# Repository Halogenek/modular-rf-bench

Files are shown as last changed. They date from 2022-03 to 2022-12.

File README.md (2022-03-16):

# Modular RF Bench

I came across an awesome system for rapid prototyping RF and Microwave solutions
by connecting individual components on small PCBs, just like LEGO.
This [Modular building block system for RF and microwave design of prototypes](https://patents.google.com/patent/US10784633B2/en?assignee=X-Microwave&oq=X-Microwave) is in my opinion a very clever way of building RF
circuits. On their [website](https://www.xmicrowave.com/) the sell almost every
available modern RF IC or passive network in a form of a rectangle PCBs.
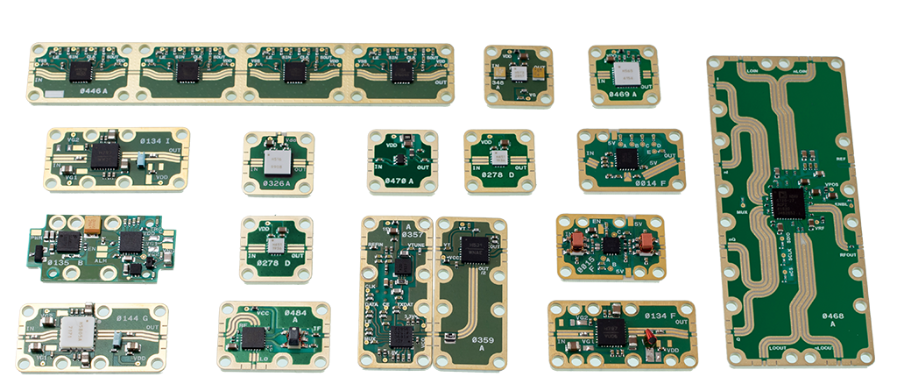
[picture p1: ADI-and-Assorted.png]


The whole system is well polished and every part has some sort of improvement.
For example the boards interconnection has a ground cutout, probably for better
impedance matching. The connection is done (according to their patent) with a
small piece with diamond particles that improve contact. That's why they claim
that this system can be used up to ~67 GHz.

Of course this performance comes at a price.

# My own design
I liked this idea so much that I wanted to check how *bad* will standard FR4
boards perform if someone would make a system like this one. But without all
those whistles.

So I made ten different designs inspired by that system. Ordered it on PcbWay.
And when will it arrive I will test it with my VNA.
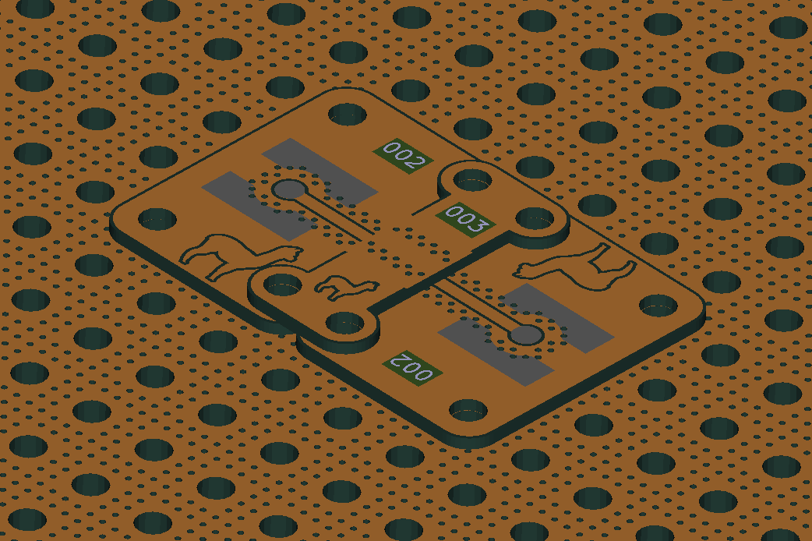
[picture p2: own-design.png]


---
After some time the boards arrived in decent quality. I soldered SMA connectors
to two boards designed for them and screwed them to the PCB base, together with
a small interconnecting PCB.

I tried to follow X Microwave design but my idea had some problems. The small
board with the number 011 that was designed to connect other boards didn't make
good contact after mounted with screws. It just bulged up and the center signal
trace didn't touched the traces on the other PCBs. But after adding a small
amount of solder to the trace it started to work.

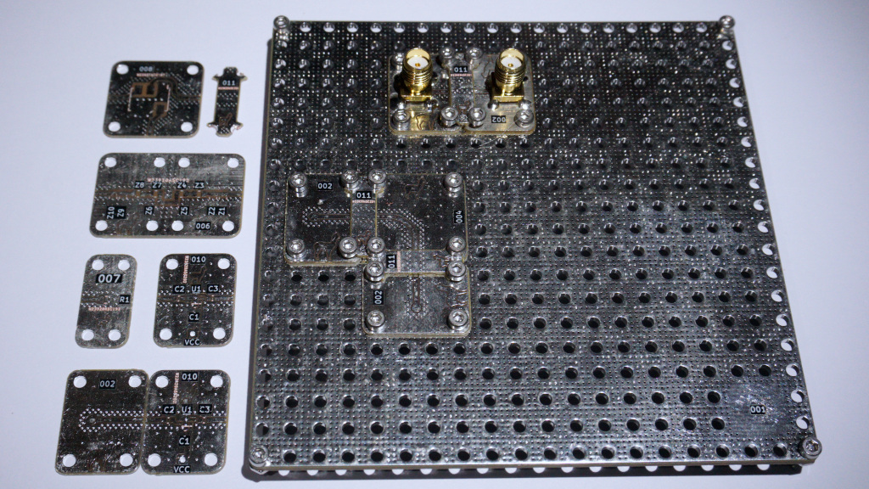
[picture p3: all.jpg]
All ordered boards

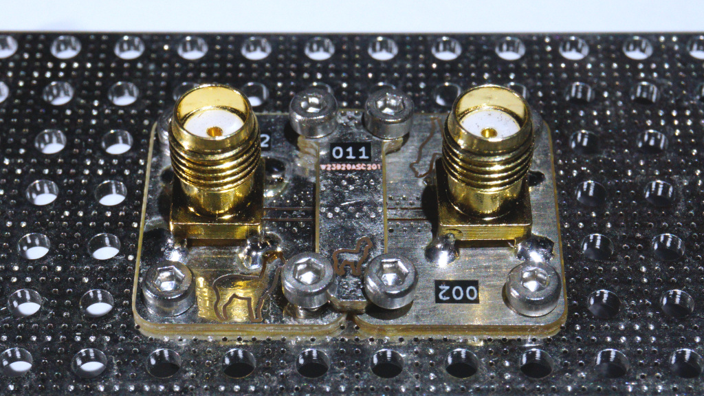
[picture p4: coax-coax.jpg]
Coax to coax connection

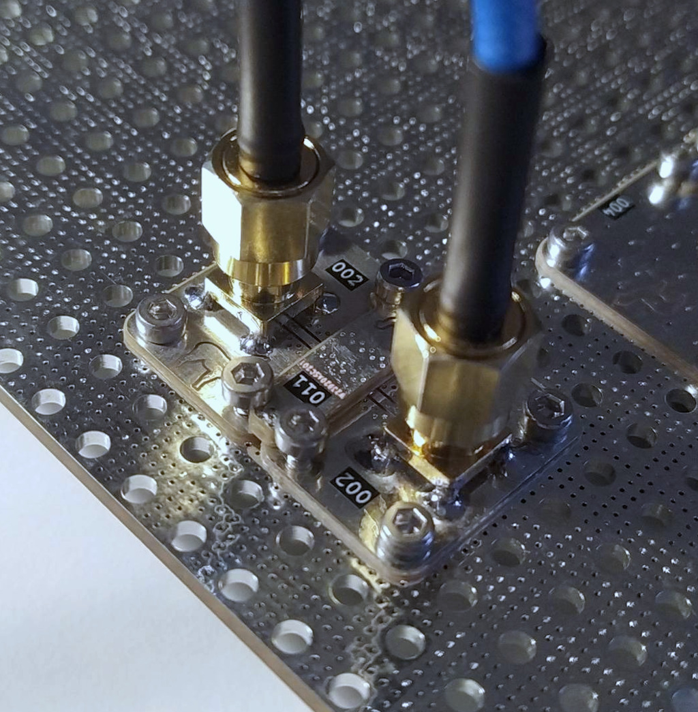
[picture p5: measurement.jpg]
Transmission line measurement


## Measurements
### Measurements of two connected SMA adapters done on nanoVNA.
*S11 50 Ohm termination*
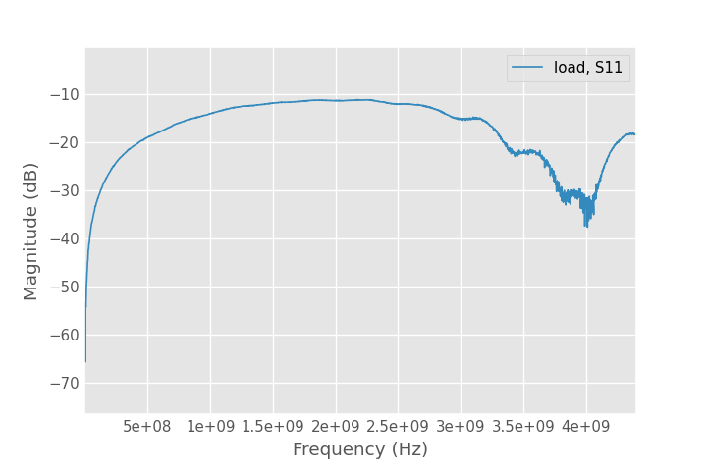
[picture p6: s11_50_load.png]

*S11 50 Ohm termination by Port 2 of nanoVNA*
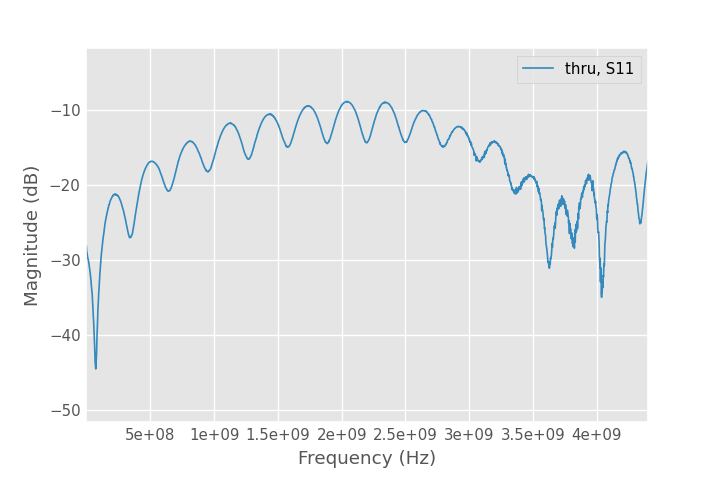
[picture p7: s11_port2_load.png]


### Measurements of two connected SMA adapters done on better VNA.
*S11 50 Ohm termination*
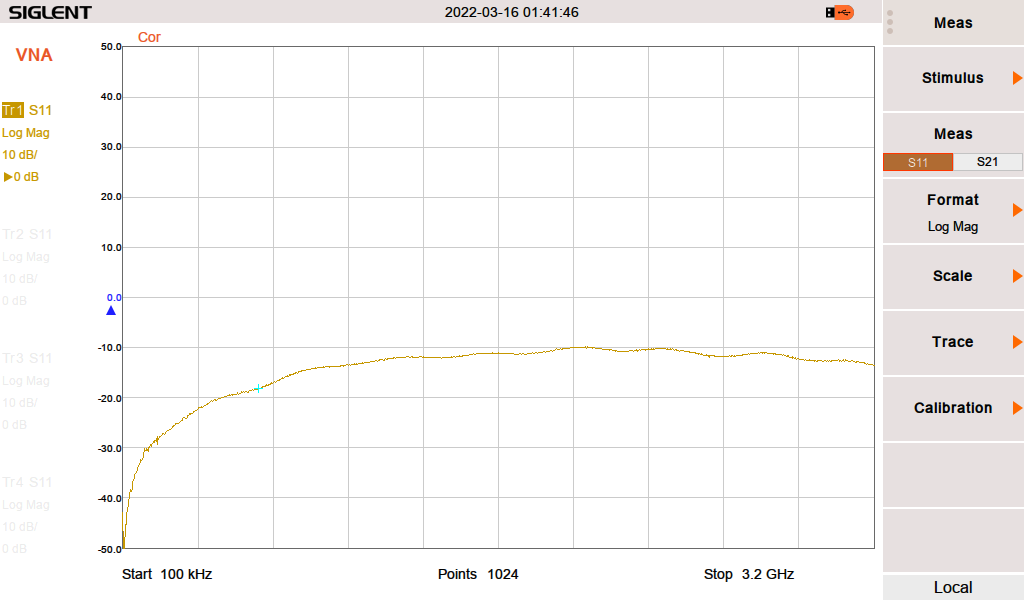
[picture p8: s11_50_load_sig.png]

*S11 50 Ohm termination by Port 2 of VNA*
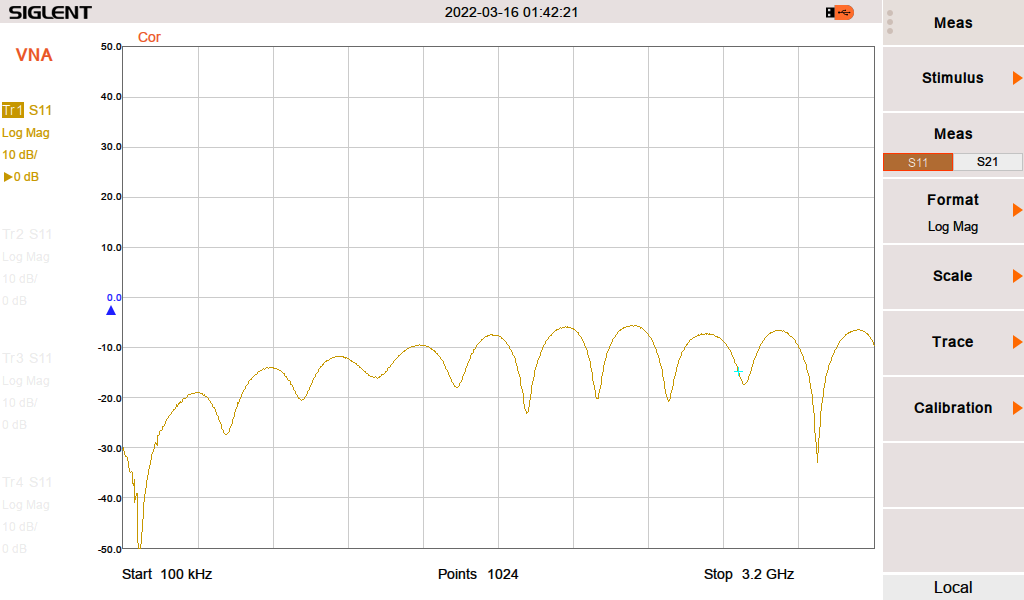
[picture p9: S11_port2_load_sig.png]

*S21*
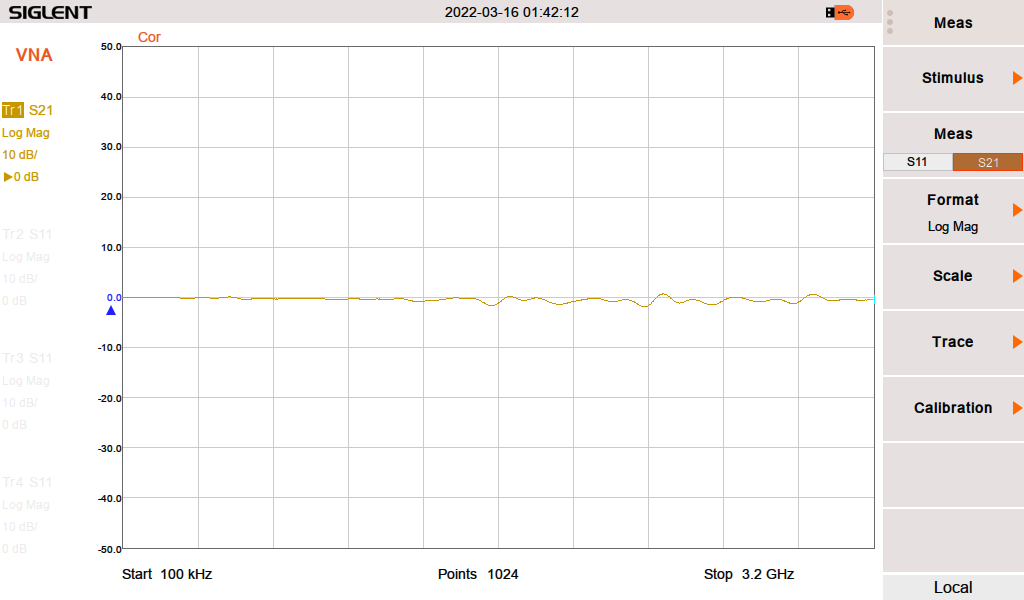
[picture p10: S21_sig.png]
S21 measurement


I wasn't excepting much after 0,8 mm FR4 PCB but it is usable up to 1,5 GHz.
The board to board connection is working and everything is pretty durable.

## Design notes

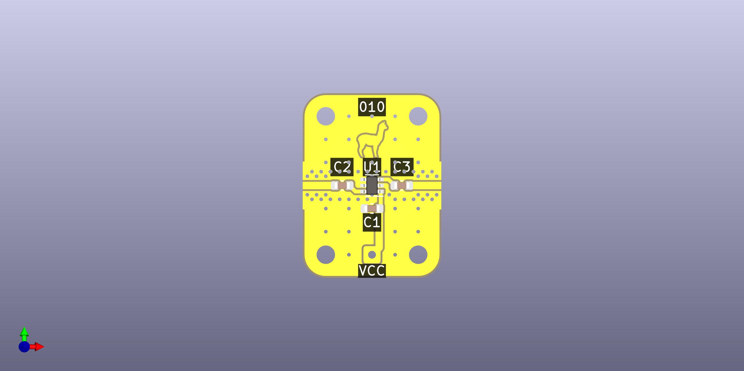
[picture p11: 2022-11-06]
src/010-amplifier/production-files/amplifier-top.jpg

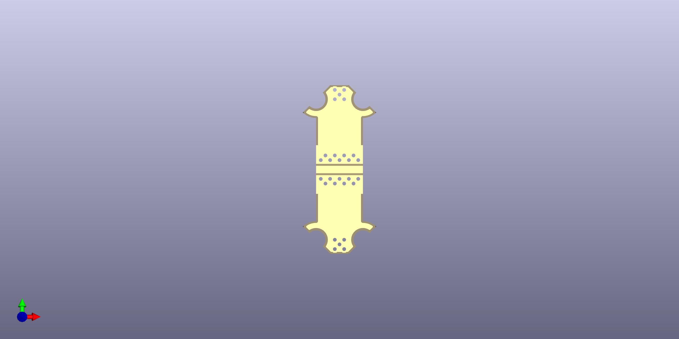
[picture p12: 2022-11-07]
src/011-pcb-connector-castalation/production-files/pcb-connector-top.jpg

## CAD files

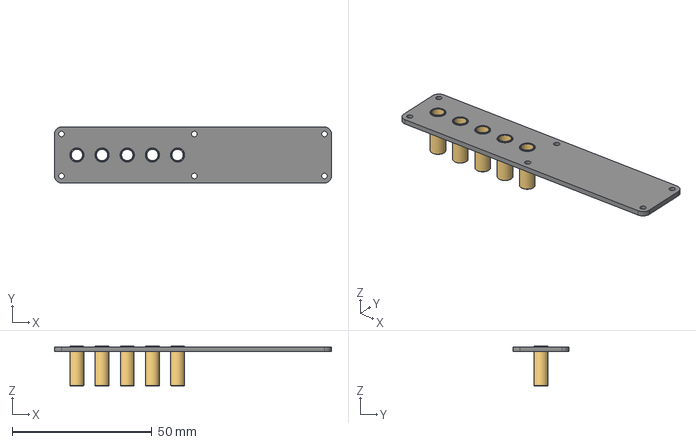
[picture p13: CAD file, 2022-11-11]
src/016-plastic-base-housing/014-base-power-board.step
99.0 x 20.0 x 14.2 mm
014-base-power-board PCB

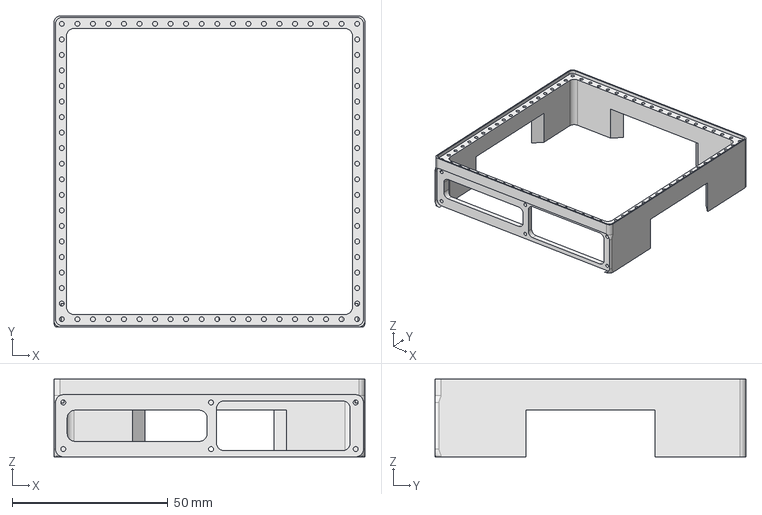
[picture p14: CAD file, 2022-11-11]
src/016-plastic-base-housing/production-files/016-plastic-base-housing.step
100.0 x 100.0 x 25.0 mm

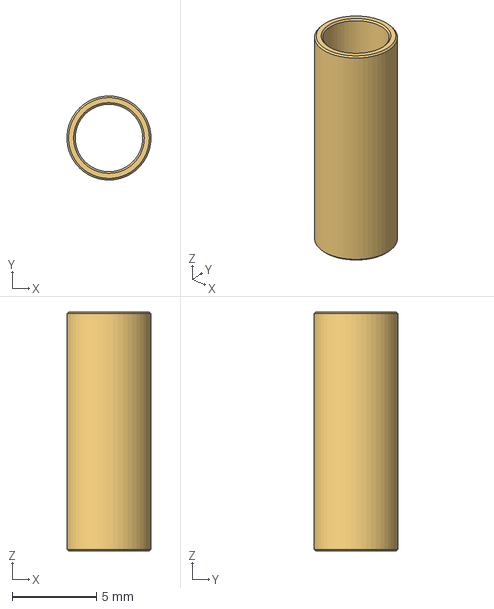
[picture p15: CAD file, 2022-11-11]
src/modular-rf-bench-3d-models/GC4012-F/GC4012-F.step
5.00 x 5.00 x 14.2 mm

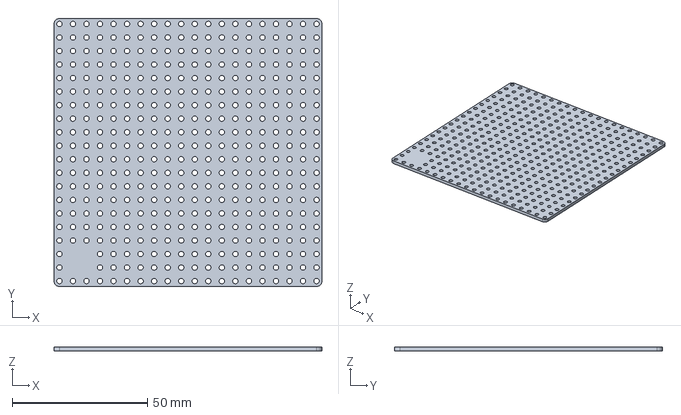
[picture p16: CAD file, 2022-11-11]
src/016-plastic-base-housing/001-base.step
99.0 x 99.0 x 1.60 mm

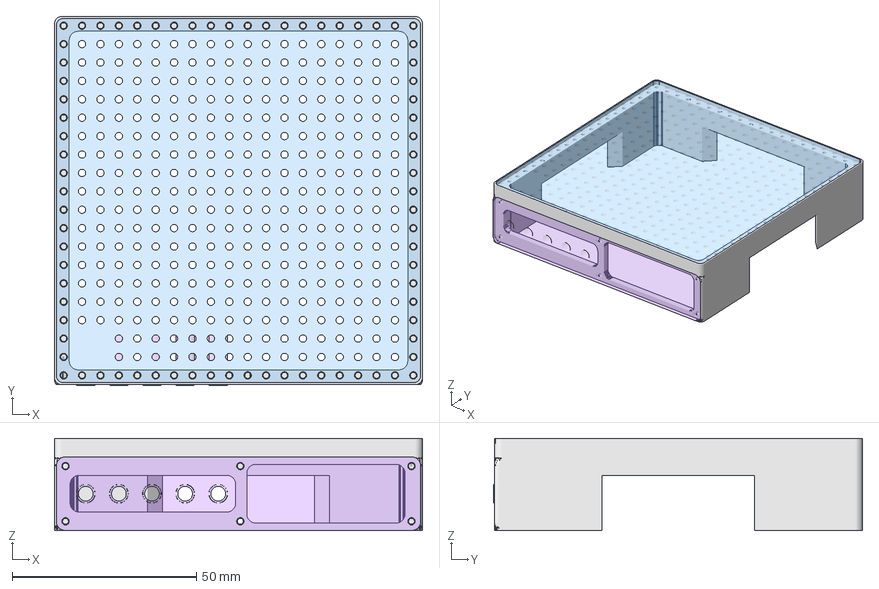
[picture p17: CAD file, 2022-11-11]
src/016-plastic-base-housing/016-plastic-base-housing.FCStd
100.0 x 100.2 x 25.0 mm
001-base 1
014-base-power-board
Body (Meshed)

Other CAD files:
src/016-plastic-base-housing/production-files/016-plastic-base-housing.stl
src/modular-rf-bench-3d-models/GC4012-F/GC4012-F.FCStd

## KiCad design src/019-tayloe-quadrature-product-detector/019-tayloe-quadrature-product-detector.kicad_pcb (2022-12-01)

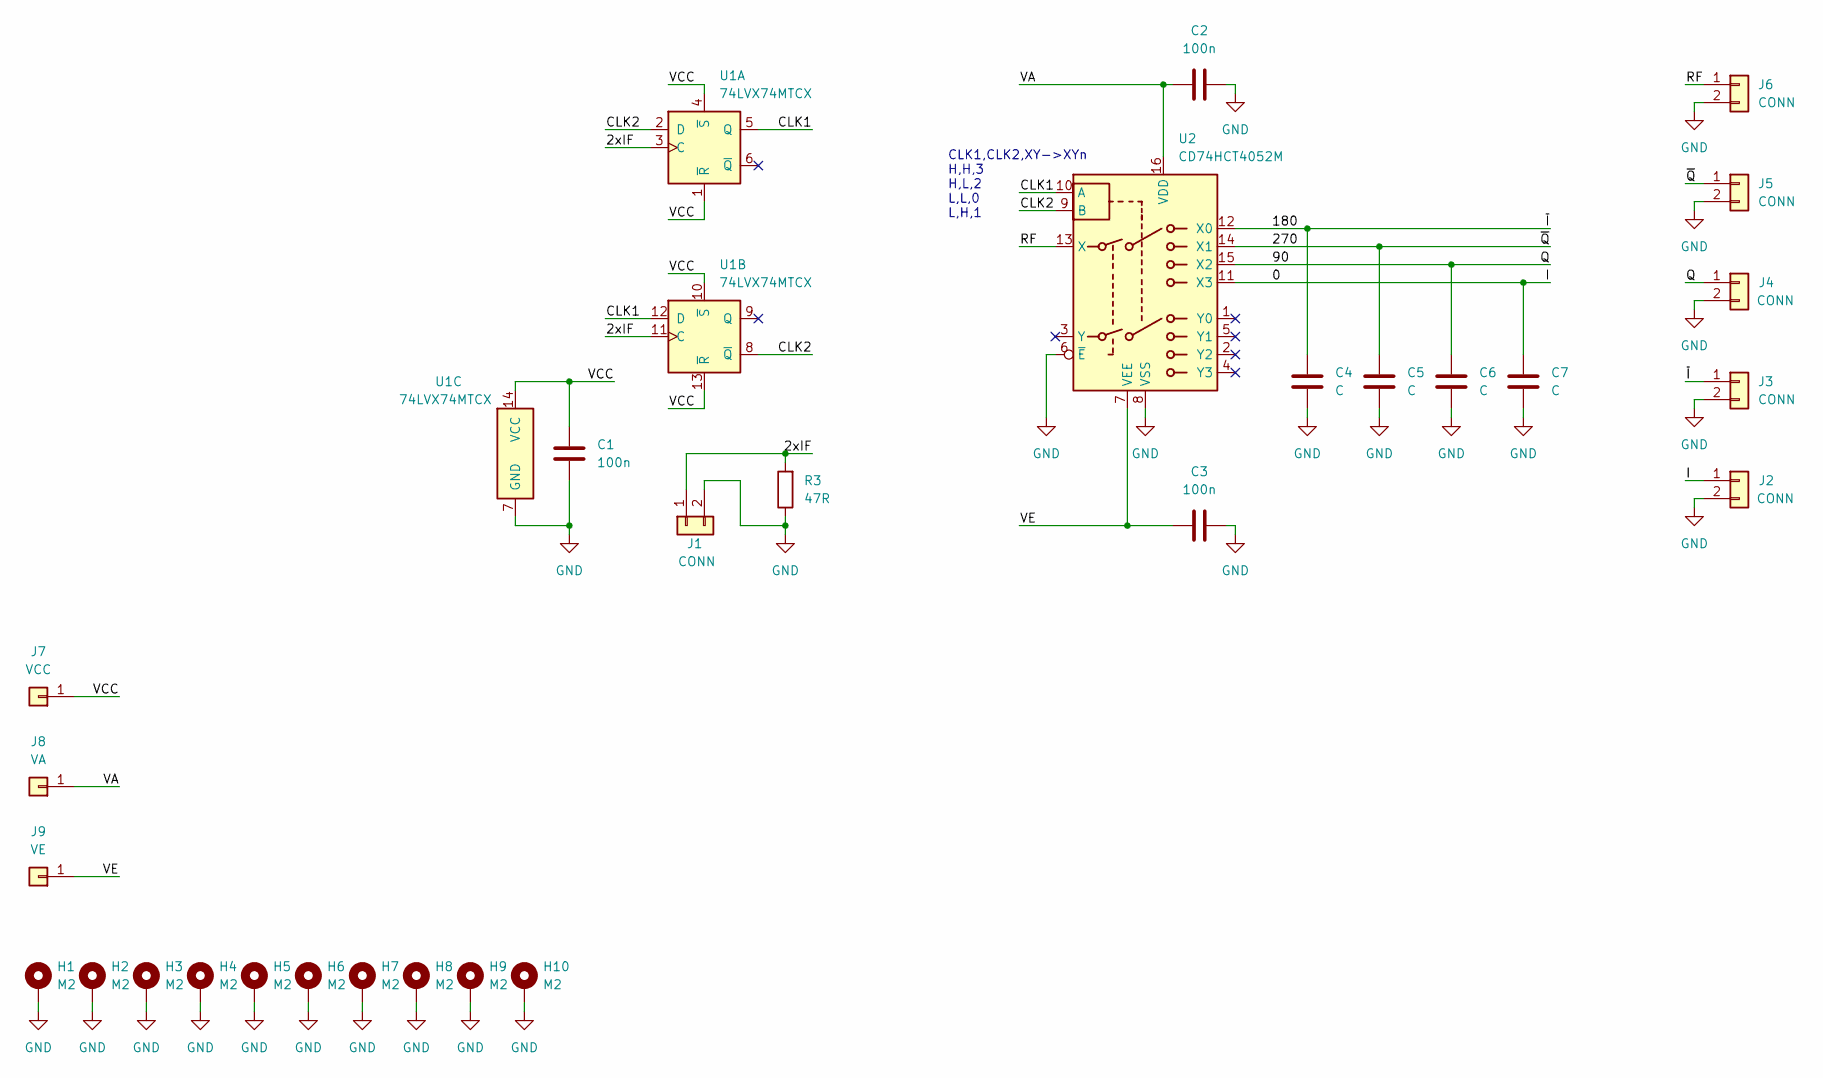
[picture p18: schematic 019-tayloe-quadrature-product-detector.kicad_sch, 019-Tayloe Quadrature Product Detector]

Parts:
C1, C2, C3: 100n; C_0603_1608Metric
C4, C5, C6, C7: C; C_0603_1608Metric
H1, H2, H3, H4, H5, H6, H7, H8, H9, H10: M2; M2-hole
J1, J2, J3, J4, J5, J6: CONN; edge-connector
J7: VCC; PWR_PIN
J8: VA; PWR_PIN
J9: VE; PWR_PIN
R3: 47R; R_0603_1608Metric
U1: 74LVX74MTCX; TSSOP-14_4.4x5mm_P0.65mm
U2: CD74HCT4052M; SO-16_3.9x9.9mm_P1.27mm

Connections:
/0: C7.1, J2.1, U2.11 (X3)
/2xIF: J1.1, R3.2, U1.3 (C), U1.11 (C)
/90: C6.1, J4.1, U2.15 (X2)
/180: C4.1, J3.1, U2.12 (X0)
/270: C5.1, J5.1, U2.14 (X1)
/CLK1: U1.5 (Q), U1.12 (D), U2.10 (A)
/CLK2: U1.2 (D), U1.8 (~Q), U2.9 (B)
/RF: J6.1, U2.13 (X)
/VA: C2.1, J8.1, U2.16 (VDD)
/VCC: C1.1, J7.1, U1.1 (~R), U1.4 (~S), U1.10 (~S), U1.13 (~R), U1.14 (VCC)
/VE: C3.1, J9.1, U2.7 (VEE)
GND: C1.2, C2.2, C3.2, C4.2, C5.2, C6.2, C7.2, H1.1, H2.1, H3.1, H4.1, H5.1, H6.1, H7.1, H8.1, H9.1, H10.1, J1.2, J2.2, J3.2, J4.2, J5.2, J6.2, R3.1, U1.7 (GND), U2.6 (~E), U2.8 (VSS)

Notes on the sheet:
CLK1,CLK2,XY->XYn H,H,3 H,L,2 L,L,0 L,H,1

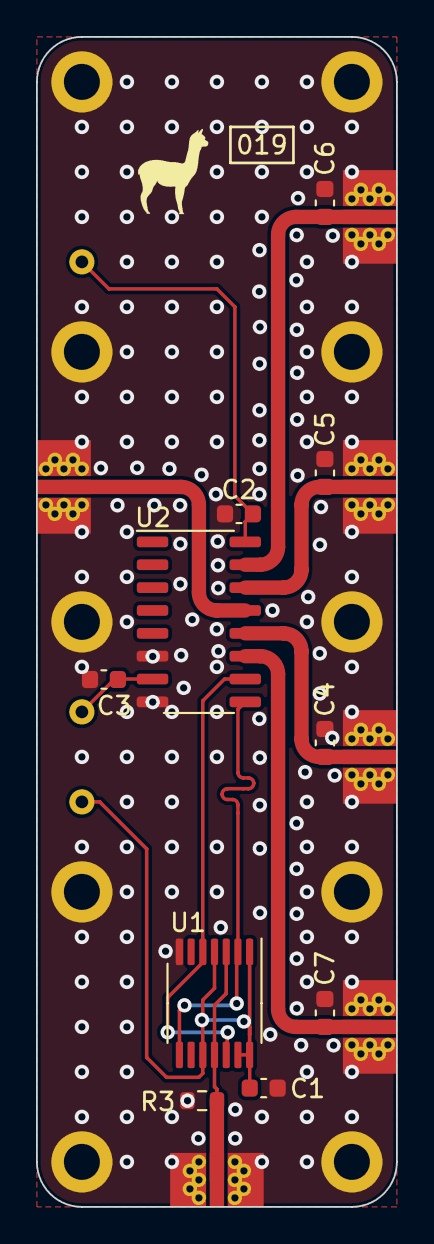
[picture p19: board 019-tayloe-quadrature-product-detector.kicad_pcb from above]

Board: 2 copper layers, 20.0 x 65.0 mm, 29 parts (0 on the bottom side), 12 nets.

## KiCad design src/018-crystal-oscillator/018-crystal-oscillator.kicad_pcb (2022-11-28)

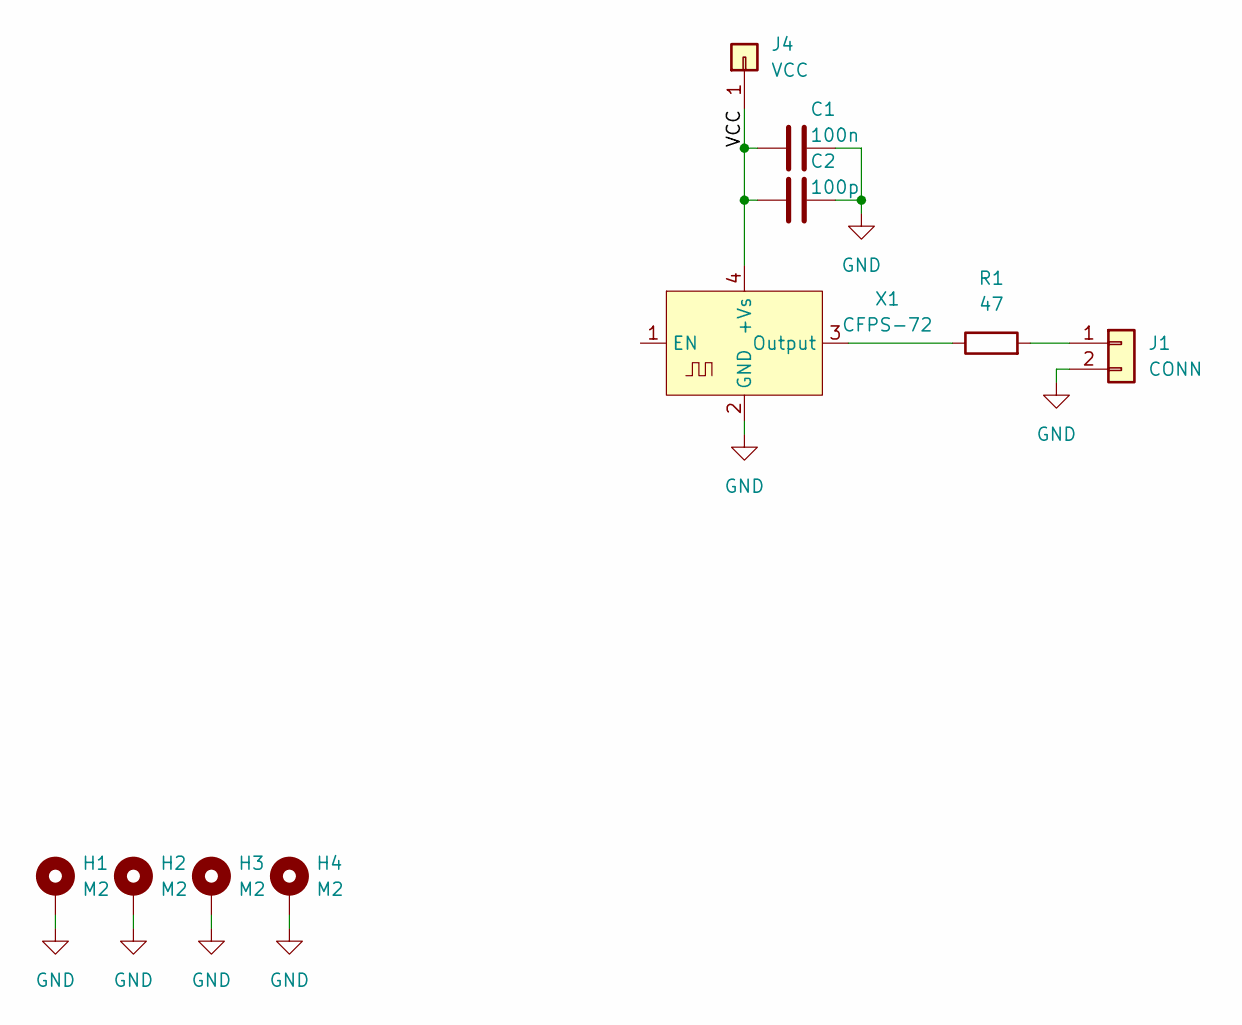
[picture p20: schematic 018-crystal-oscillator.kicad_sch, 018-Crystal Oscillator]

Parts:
C1: 100n; C_0603_1608Metric
C2: 100p; C_0603_1608Metric
H1, H2, H3, H4: M2; M2-hole
J1: CONN; edge-connector
J4: VCC
R1: 47; R_0603_1608Metric
X1: CFPS-72; Oscillator_SMD_IQD_IQXO70-4Pin_7.5x5.0mm

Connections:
/VCC: C1.1, C2.1, J4.1, X1.4 (+Vs)
GND: C1.2, C2.2, H1.1, H2.1, H3.1, H4.1, J1.2, X1.2 (GND)
unnamed: J1.1, R1.2
unnamed: R1.1, X1.3 (Output)

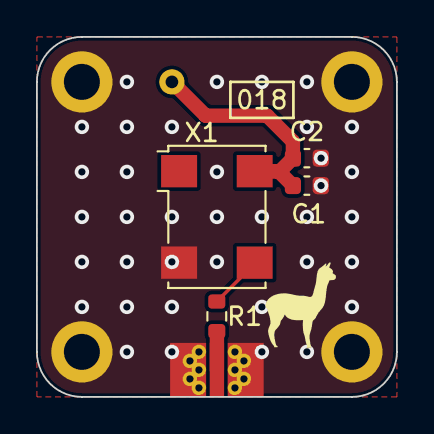
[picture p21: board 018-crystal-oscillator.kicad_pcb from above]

Board: 2 copper layers, 20.0 x 20.0 mm, 10 parts (0 on the bottom side), 4 nets.

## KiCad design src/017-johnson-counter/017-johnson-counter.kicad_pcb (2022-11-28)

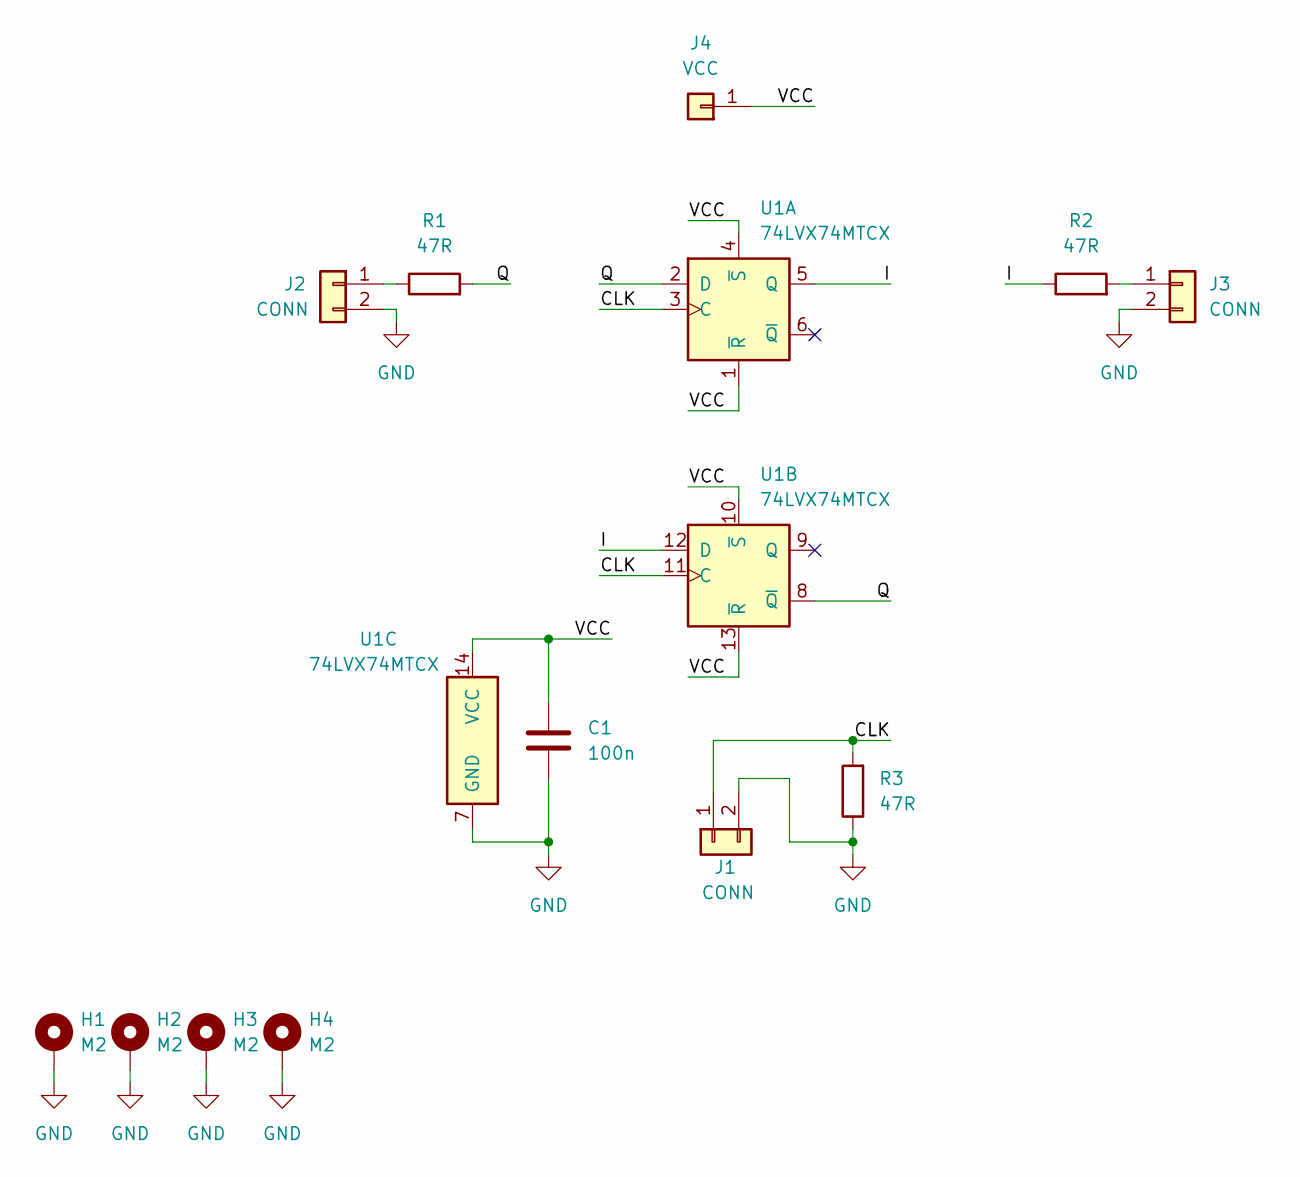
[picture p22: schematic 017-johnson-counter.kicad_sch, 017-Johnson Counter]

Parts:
C1: 100n; C_0603_1608Metric
H1, H2, H3, H4: M2; M2-hole
J1, J2, J3: CONN; edge-connector
J4: VCC
R1, R2, R3: 47R; R_0603_1608Metric
U1: 74LVX74MTCX; TSSOP-14_4.4x5mm_P0.65mm

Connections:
/CLK: J1.1, R3.2, U1.3 (C), U1.11 (C)
/I: R2.1, U1.5 (Q), U1.12 (D)
/Q: R1.2, U1.2 (D), U1.8 (~Q)
/VCC: C1.1, J4.1, U1.1 (~R), U1.4 (~S), U1.10 (~S), U1.13 (~R), U1.14 (VCC)
GND: C1.2, H1.1, H2.1, H3.1, H4.1, J1.2, J2.2, J3.2, R3.1, U1.7 (GND)
unnamed: J2.1, R1.1
unnamed: J3.1, R2.2

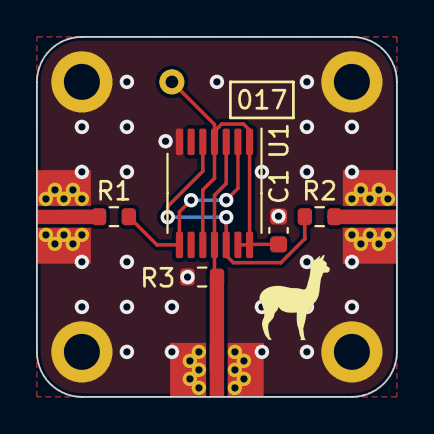
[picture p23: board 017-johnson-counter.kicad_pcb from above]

Board: 2 copper layers, 20.0 x 20.0 mm, 13 parts (0 on the bottom side), 7 nets.

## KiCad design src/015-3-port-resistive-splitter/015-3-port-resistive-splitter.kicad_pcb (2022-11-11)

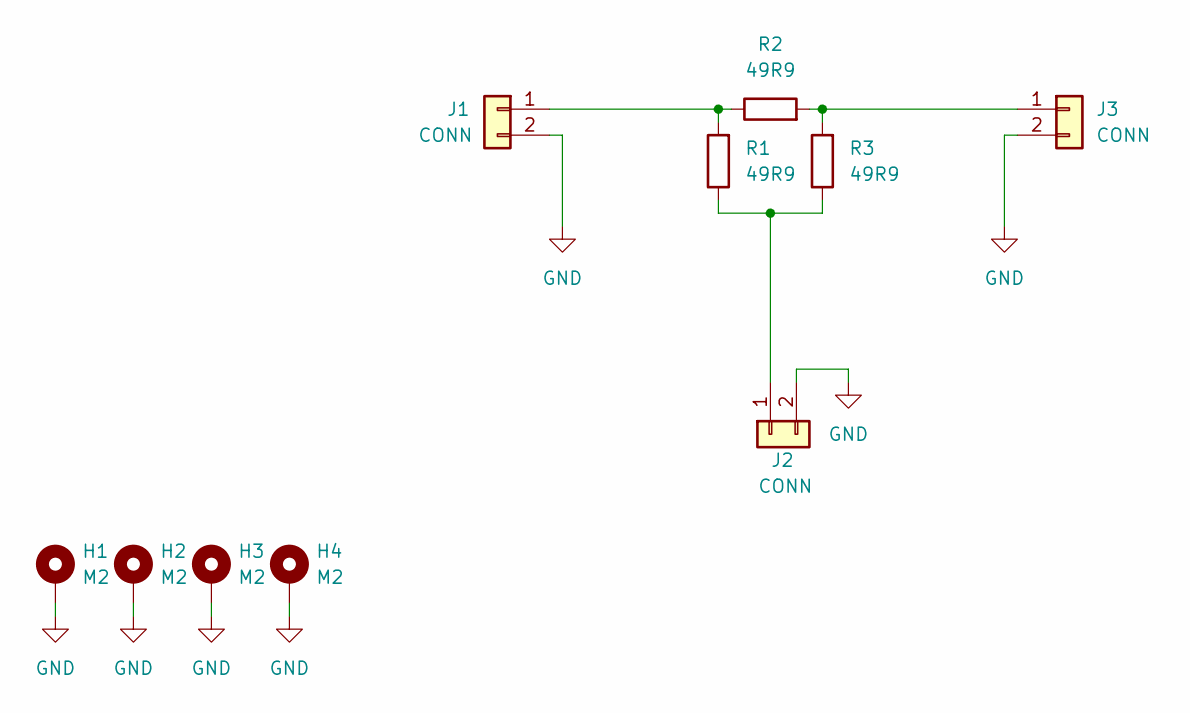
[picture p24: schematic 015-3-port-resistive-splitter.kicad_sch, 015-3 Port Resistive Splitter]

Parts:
H1, H2, H3, H4: M2; M2-hole
J1, J2, J3: CONN; edge-connector
R1, R2, R3: 49R9; R_0402_1005Metric

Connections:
GND: H1.1, H2.1, H3.1, H4.1, J1.2, J2.2, J3.2
unnamed: J1.1, R1.2, R2.1
unnamed: J2.1, R1.1, R3.1
unnamed: J3.1, R2.2, R3.2

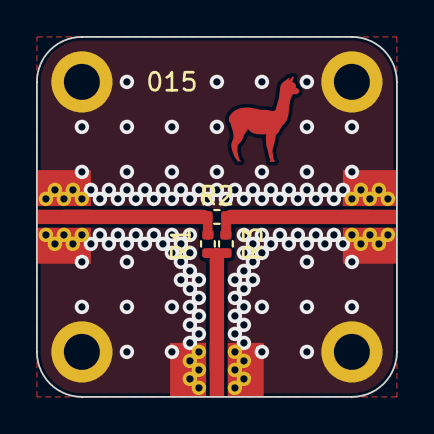
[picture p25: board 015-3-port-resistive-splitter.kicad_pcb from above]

Board: 2 copper layers, 20.0 x 20.0 mm, 10 parts (0 on the bottom side), 4 nets.

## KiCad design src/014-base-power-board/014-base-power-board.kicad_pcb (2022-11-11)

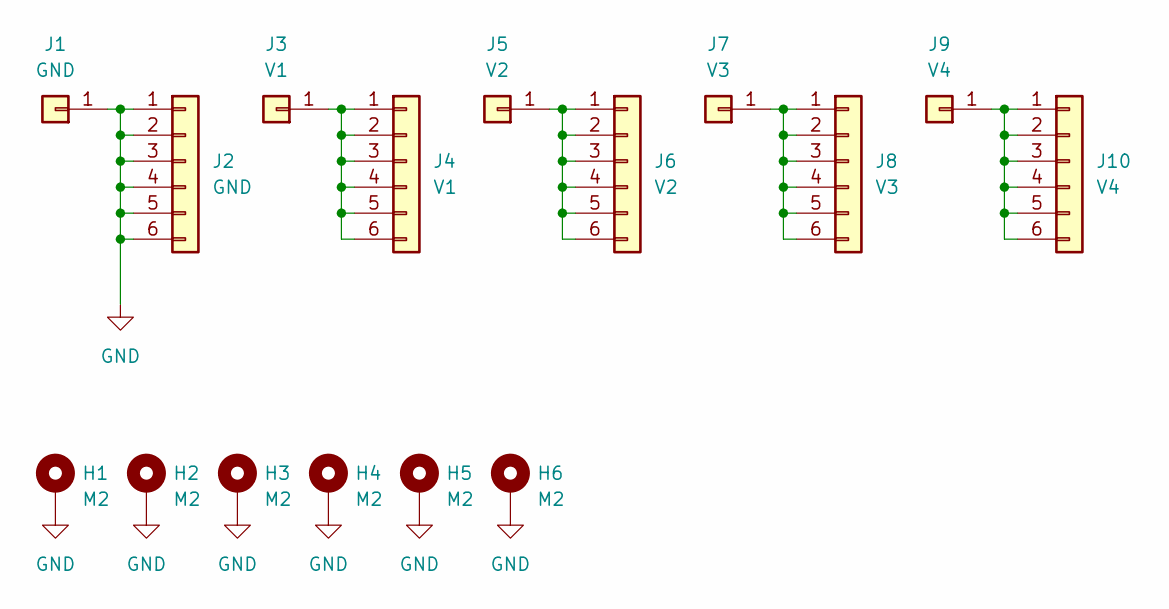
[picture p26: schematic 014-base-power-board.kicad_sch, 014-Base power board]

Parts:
H1, H2, H3, H4, H5, H6: M2; M2-hole
J1: GND; GC4012-F
J2: GND; PinHeader_1x06_P2.54mm_Vertical_SMD_Pin1Left
J3: V1; GC4012-F
J4: V1; PinHeader_1x06_P2.54mm_Vertical_SMD_Pin1Left
J5: V2; GC4012-F
J6: V2; PinHeader_1x06_P2.54mm_Vertical_SMD_Pin1Left
J7: V3; GC4012-F
J8: V3; PinHeader_1x06_P2.54mm_Vertical_SMD_Pin1Left
J9: V4; GC4012-F
J10: V4; PinHeader_1x06_P2.54mm_Vertical_SMD_Pin1Left

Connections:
GND: H1.1, H2.1, H3.1, H4.1, H5.1, H6.1, J1.1, J2.1, J2.2, J2.3, J2.4, J2.5, J2.6
unnamed: J3.1, J4.1, J4.2, J4.3, J4.4, J4.5, J4.6
unnamed: J5.1, J6.1, J6.2, J6.3, J6.4, J6.5, J6.6
unnamed: J7.1, J8.1, J8.2, J8.3, J8.4, J8.5, J8.6
unnamed: J9.1, J10.1, J10.2, J10.3, J10.4, J10.5, J10.6

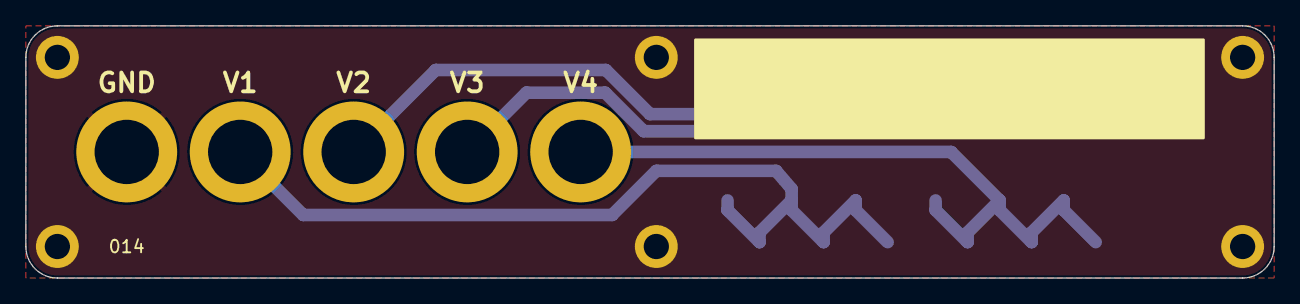
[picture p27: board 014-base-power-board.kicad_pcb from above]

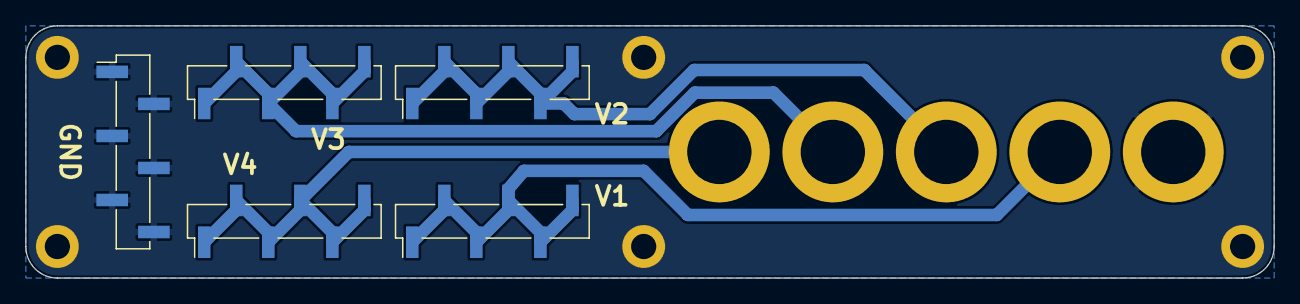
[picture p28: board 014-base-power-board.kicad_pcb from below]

Board: 2 copper layers, 99.0 x 20.0 mm, 16 parts (5 on the bottom side), 5 nets.

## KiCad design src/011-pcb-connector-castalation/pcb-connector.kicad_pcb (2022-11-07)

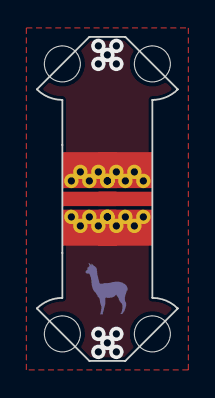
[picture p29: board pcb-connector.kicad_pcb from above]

Board: 2 copper layers, 7.8 x 18.0 mm, 6 parts (0 on the bottom side), 2 nets, no tracks yet.

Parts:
H1, H2, H3, H4: M2; M2-hole
J1, J2: CONN; edge-connector

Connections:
GND: J1.2, J2.2
unnamed: J1.1, J2.1

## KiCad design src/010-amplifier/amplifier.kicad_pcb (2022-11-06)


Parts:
C1: 22n; C_0603_1608Metric
C2, C3: 100p; C_0603_1608Metric
H1, H2, H3, H4: M2; M2-hole
J1, J3: CONN; edge-connector
J2: VCC; SolderWire-0.25sqmm_1x01_D0.65mm_OD1.7mm
U1: BGA2866; SOT-363_SC-70-6

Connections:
GND: C1.1, H1.1, H2.1, H3.1, H4.1, J1.2, J3.2, U1.2 (G), U1.4 (G), U1.5 (G)
unnamed: C1.2, J2.1, U1.1 (Vcc)
unnamed: C2.1, J1.1
unnamed: C2.2, U1.6
unnamed: C3.1, U1.3
unnamed: C3.2, J3.1


Board: 2 copper layers, 15.0 x 20.0 mm, 11 parts (0 on the bottom side), 6 nets.

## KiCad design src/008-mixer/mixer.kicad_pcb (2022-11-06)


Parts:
H1, H2, H3, H4: M2; M2-hole
J1, J2, J3: CONN; edge-connector
U1: ADEX-10; Mini-Circuits_CD542_LandPatternPL-052

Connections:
GND: H1.1, H2.1, H3.1, H4.1, J1.2, J2.2, J3.2, U1.1 (GND), U1.4 (GND), U1.5 (GND)
unnamed: J1.1, U1.3 (RF)
unnamed: J2.1, U1.6 (LO)
unnamed: J3.1, U1.2 (IF)


Board: 2 copper layers, 20.0 x 20.0 mm, 8 parts (0 on the bottom side), 4 nets.

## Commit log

2022-01-24 changing pcb connector size
    [pcb-connector-Dolna opisowa.gbr, pcb-connector-Dolna sodermaski.gbr, pcb-connector-Dolna sygnałowa.gbr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]
2022-01-27 changing base
    [base-Dolna opisowa.gbr, base-Dolna sodermaski.gbr, base-Dolna sygnałowa.gbr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]
2022-01-27 changing sma connector pcb
    [sma-connector-Dolna opisowa.gbr, sma-connector-Dolna sodermaski.gbr, sma-connector-Dolna sygnałowa.gbr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]
2022-01-27 changing pcb connector
    [pcb-connector-Dolna opisowa.gbr, pcb-connector-Dolna sodermaski.gbr, pcb-connector-Dolna sygnałowa.gbr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]
2022-01-27 creating 45 pcb turn connector
    [pcb-turn-45-Dolna sodermaski.gbr, pcb-turn-45-Dolna sygnałowa.gbr, pcb-turn-45-Górna opisowa.gbr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]
2022-01-28 changing pcb 45 turn
    [pcb-turn-45-Dolna sodermaski.gbr, pcb-turn-45-Dolna sygnałowa.gbr, pcb-turn-45-Górna opisowa.gbr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]
2022-01-28 starting pcb connector x2 project
    [pcb-connector-x2.kicad_pcb, pcb-connector-x2.kicad_sch]
2022-01-28 changing pcb connector x2 location
    [pcb-connector-x2.kicad_pcb, pcb-connector-x2.kicad_sch]
2022-01-29 adding filter pcb and load
    [filter-Dolna sodermaski.gbr, filter-Dolna sygnałowa.gbr, filter-Górna opisowa.gbr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]
2022-01-29 changing gerber layer names and fixing edge connector footprint
    [base-B_Cu.gbr, base-B_Mask.gbr, base-B_Silkscreen.gbr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]
2022-01-30 creating balanced mixer pcb
    [mixer-B_Cu.gbr, mixer-B_Mask.gbr, mixer-Edge_Cuts.gbr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]
2022-01-30 adding 009 pcb connector x3
    [pcb-connector-x3-B_Cu.gbr, pcb-connector-x3-B_Mask.gbr, pcb-connector-x3-B_Silkscreen.gbr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]
2022-01-30 adding 010 amplifier
    [amplifier-B_Cu.gbr, amplifier-B_Mask.gbr, amplifier-Edge_Cuts.gbr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]
2022-01-31 adding different pcb connector 011
    [pcb-connector-B_Cu.gbr, pcb-connector-B_Mask.gbr, pcb-connector-B_Silkscreen.gbr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]
2022-02-01 fixing silkscreen in gerber files for 010
    [amplifier-B_Cu.gbr, amplifier-B_Mask.gbr, amplifier-Edge_Cuts.gbr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]
2022-03-06 fix 010-amplifier VCC pad size due short to base
    [amplifier-B_Cu.gbr, amplifier-B_Mask.gbr, amplifier-Edge_Cuts.gbr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]
2022-03-13 starting script for rendering the top view of the PCBs
    [test.kicad_pcb]
2022-03-13 adding scottbez's tools for generating images of the PCBs - modifications needed
2022-11-06 Update M2 hole size in 001 base plate
    [base-B_Cu.gbr, base-B_Mask.gbr, base-B_Silkscreen.gbr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]
2022-11-06 Update M2 footprint. Update M2 hole size in 002.
    [base.step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]
2022-11-06 Update M2 hole size in 004. Remove 003.
    [pcb-connector-B_Cu.gbr, pcb-connector-B_Mask.gbr, pcb-connector-B_Silkscreen.gbr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]
2022-11-06 Remove 005.
    [pcb-connector-x2-B_Cu.gbr, pcb-connector-x2-B_Mask.gbr, pcb-connector-x2-B_Silkscreen.gbr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]
2022-11-06 Update M2 hole size in 006.
    [filter-B_Cu.gbr, filter-B_Mask.gbr, filter-B_Silkscreen.gbr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]
2022-11-06 Update M2 hole size in 007.
    [load-B_Cu.gbr, load-B_Mask.gbr, load-B_Silkscreen.gbr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]
2022-11-06 Update M2 hole size in 008.
    [mixer-B_Cu.gbr, mixer-B_Mask.gbr, mixer-B_Silkscreen.gbr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]
2022-11-06 Removing 009.
    [pcb-connector-x3-B_Cu.gbr, pcb-connector-x3-B_Mask.gbr, pcb-connector-x3-B_Silkscreen.gbr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]
2022-11-06 Update M2 hole size in 010.
    [amplifier-B_Cu.gbr, amplifier-B_Mask.gbr, amplifier-B_Silkscreen.gbr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]
2022-11-07 Update M2 hole size and type in 011.
    [pcb-connector-B_Cu.gbr, pcb-connector-B_Mask.gbr, pcb-connector-B_Silkscreen.gbr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]
2022-11-07 Fixing footprint library linking
2022-11-07 Creating 012 prototype board
    [012-prototype-board-B_Cu.gbr, 012-prototype-board-B_Mask.gbr, 012-prototype-board-B_Silkscreen.gbr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]
2022-11-08 Finishing first version of python script for SVG PCB view generation
    [base.kicad_pcb]
2022-11-09 Creating 013-prototype board
    [013-prototype-board-B_Cu.gbr, 013-prototype-board-B_Mask.gbr, 013-prototype-board-B_Silkscreen.gbr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]
2022-11-11 Adding 014-base-power-board
    [014-base-power-board-B_Cu.gbr, 014-base-power-board-B_Mask.gbr, 014-base-power-board-B_Silkscreen.gbr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]
2022-11-11 Fixing VCC hole size on development boards
    [012-prototype-board-B_Cu.gbr, 012-prototype-board-B_Mask.gbr, 012-prototype-board-B_Silkscreen.gbr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]
2022-11-11 Adding 3 way power splitter
    [015-3-port-resistive-splitter-B_Cu.gbr, 015-3-port-resistive-splitter-B_Mask.gbr, 015-3-port-resistive-splitter-B_Silkscreen.gbr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]
2022-11-11 Creating plastic 3D printed housing for 001-base PCB
    [001-base.step, 014-base-power-board.step, 016-plastic-base-housing.FCStd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]
2022-11-28 017 Johnson Counter
    [017-johnson-counter-B_Cu.gbr, 017-johnson-counter-B_Mask.gbr, 017-johnson-counter-B_Silkscreen.gbr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]
2022-11-28 018 crystal oscillator
    [018-crystal-oscillator-B_Cu.gbr, 018-crystal-oscillator-B_Mask.gbr, 018-crystal-oscillator-B_Silkscreen.gbr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]
